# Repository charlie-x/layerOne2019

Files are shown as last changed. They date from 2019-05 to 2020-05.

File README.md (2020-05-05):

View this project on [CADLAB.io](https://cadlab.io/project/22870). 

# layerOne2019
LayerOne 2019 conference www.layerone.org

firmware - folder for kitbadge L1 LOGO see notes in there, 

MOSI, MISO, SCK, VCC, RST, GND

MOSI is closest to top of badge.

firmware for esp32 camera board

https://github.com/m5stack

https://www.youtube.com/watch?v=pfQ5VgcnJhg

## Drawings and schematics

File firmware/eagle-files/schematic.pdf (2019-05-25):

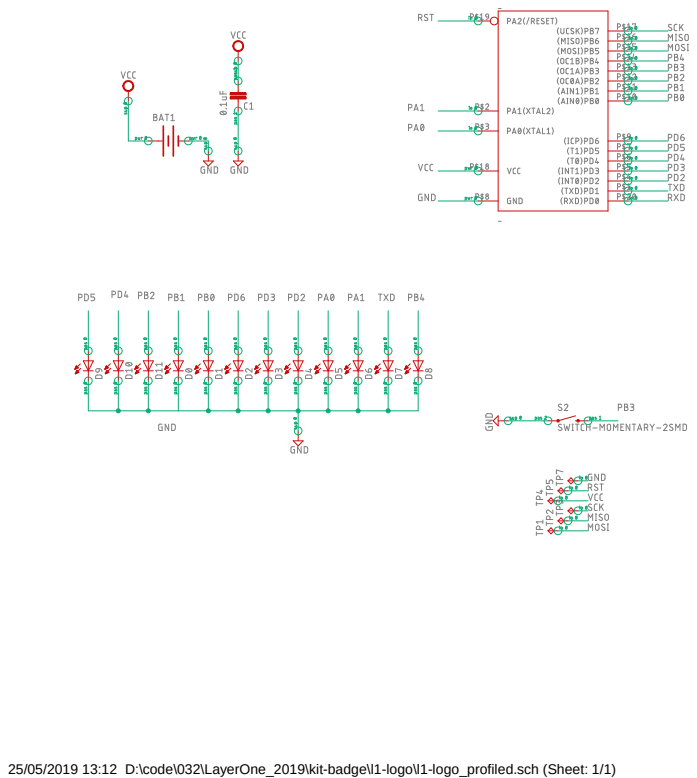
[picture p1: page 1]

25/05/2019 13:12 D:\code\032\LayerOne_2019\kit-badge\l1-logo\l1-logo_profiled.sch (Sheet: 1/1)

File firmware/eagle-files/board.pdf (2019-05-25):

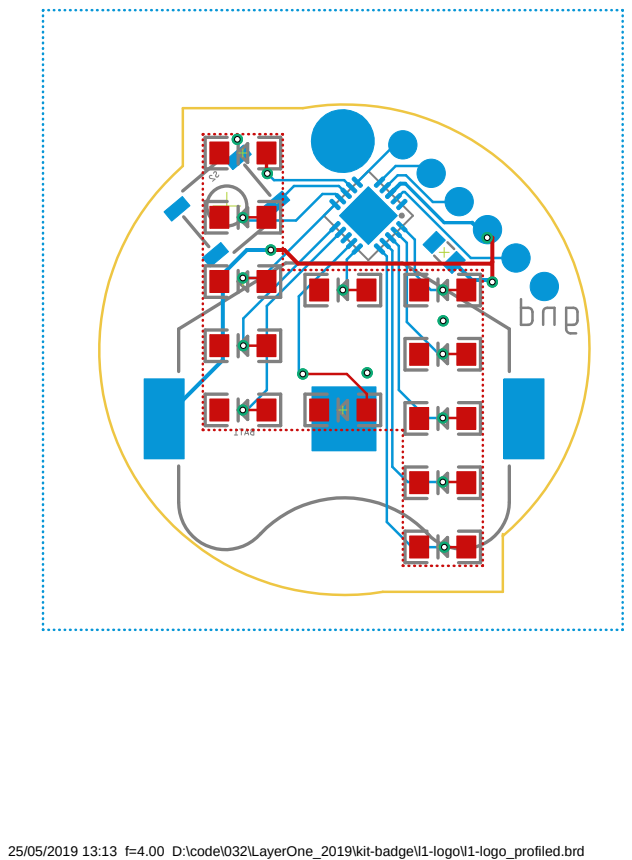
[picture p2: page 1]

25/05/2019 13:13 f=4.00 D:\code\032\LayerOne_2019\kit-badge\l1-logo\l1-logo_profiled.brd

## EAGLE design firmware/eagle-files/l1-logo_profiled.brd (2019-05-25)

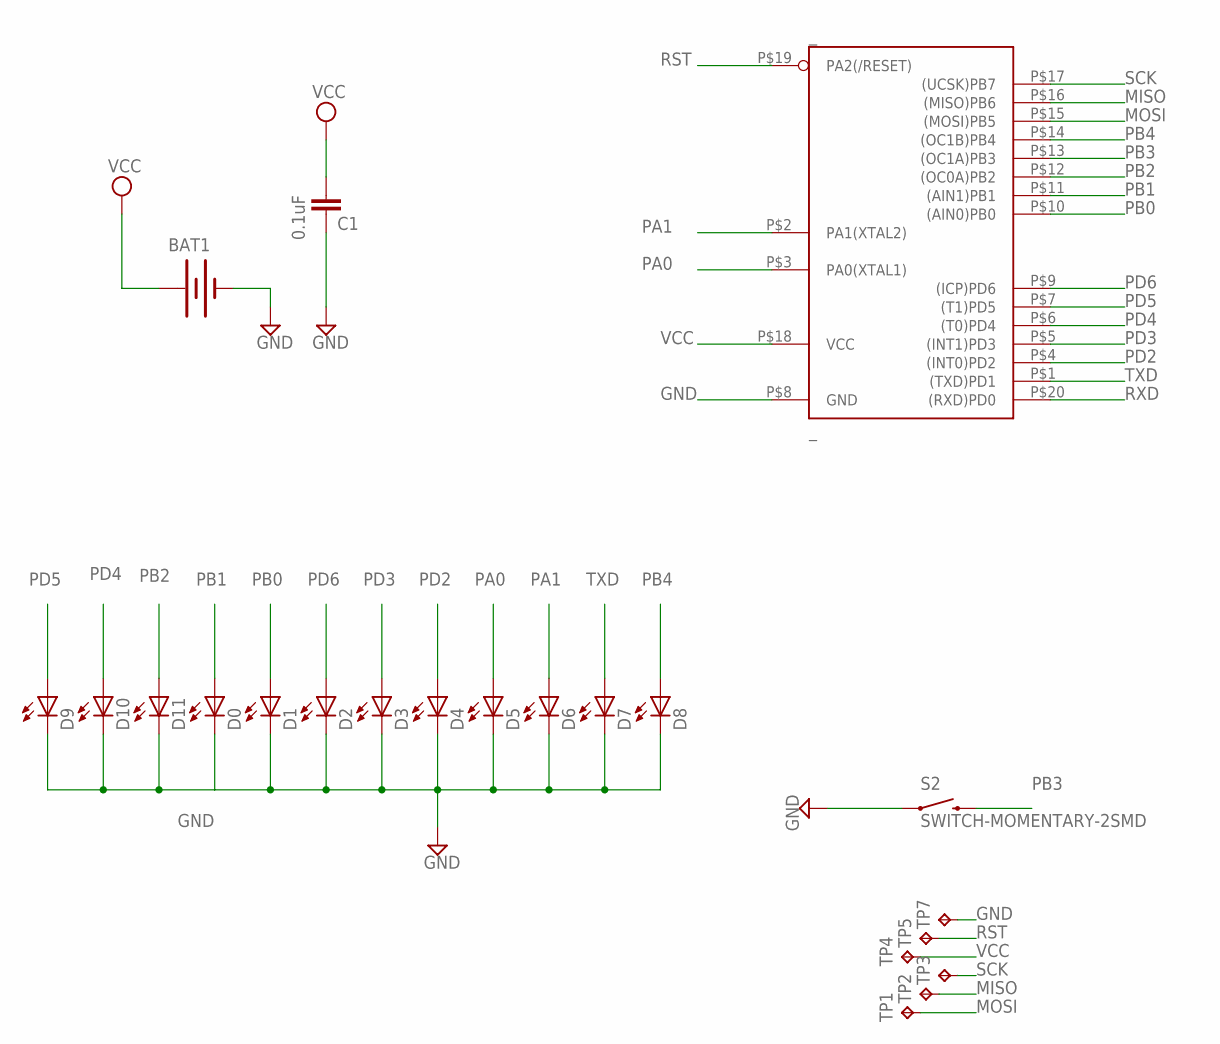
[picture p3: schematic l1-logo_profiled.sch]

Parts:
BAT1: SPARKFUN_BATTERYSPARKFUN_BATTCOMM_20MM_LINX; SPARKFUN_BATTCOM_20MM_LINX
C1: 0.1uF; 0805
D0, D1, D2, D3, D4, D5, D6, D7, D8, D9, D10, D11: SPARKFUN_LED1206; SPARKFUN_LED-1206
S2: SWITCH-MOMENTARY-2SMD; TACTILE_SWITCH_SMD
TP1, TP2, TP3, TP4, TP5, TP7: TPTP18R; TP18R
_: _; MLF20

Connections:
GND: BAT1.2 (-), C1.2, D0.C, D1.C, D2.C, D3.C, D4.C, D5.C, D6.C, D7.C, D8.C, D9.C, D10.C, D11.C, S2.1, TP7.TP, _.P$8 (GND)
MISO: TP2.TP, _.P$16 ((MISO)PB6)
MOSI: TP1.TP, _.P$15 ((MOSI)PB5)
PA0: D5.A, _.P$3 (PA0(XTAL1))
PA1: D6.A, _.P$2 (PA1(XTAL2))
PB0: D1.A, _.P$10 ((AIN0)PB0)
PB1: D0.A, _.P$11 ((AIN1)PB1)
PB2: D11.A, _.P$12 ((OC0A)PB2)
PB3: S2.3 (2), _.P$13 ((OC1A)PB3)
PB4: D8.A, _.P$14 ((OC1B)PB4)
PD2: D4.A, _.P$4 ((INT0)PD2)
PD3: D3.A, _.P$5 ((INT1)PD3)
PD4: D10.A, _.P$6 ((T0)PD4)
PD5: D9.A, _.P$7 ((T1)PD5)
PD6: D2.A, _.P$9 ((ICP)PD6)
RST: TP5.TP, _.P$19 (PA2(/RESET))
RXD: _.P$20 ((RXD)PD0)
SCK: TP3.TP, _.P$17 ((UCSK)PB7)
TXD: D7.A, _.P$1 ((TXD)PD1)
VCC: BAT1.1 (+), C1.1, TP4.TP, _.P$18 (VCC)

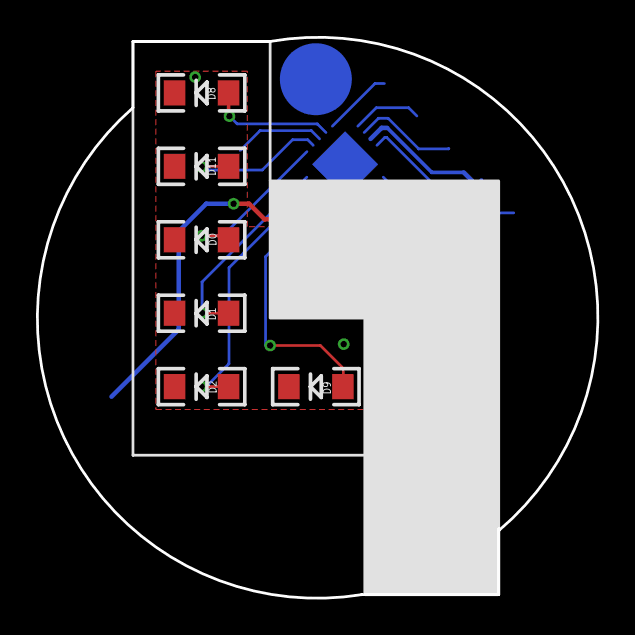
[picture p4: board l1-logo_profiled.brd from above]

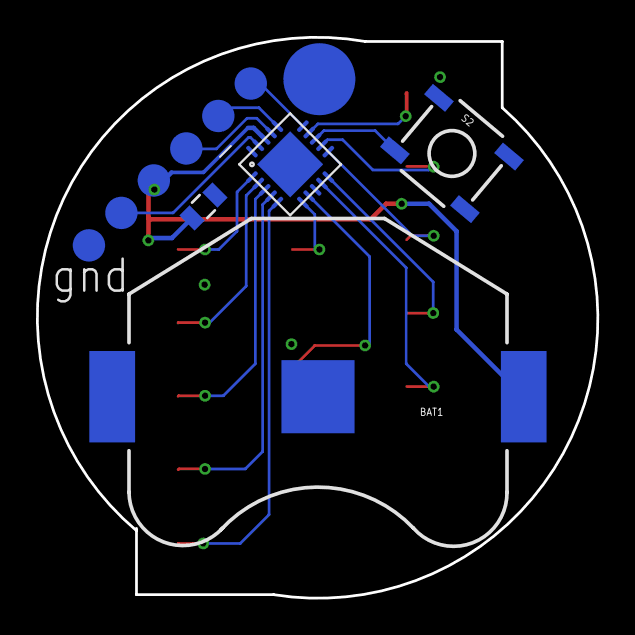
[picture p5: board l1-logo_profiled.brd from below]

Board: 2 copper layers, 31.1 x 31.2 mm, 22 parts (10 on the bottom side), 19 nets.

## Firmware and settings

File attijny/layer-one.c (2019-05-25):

/*
	SELFPRGEN = [ ]
	DWEN = [ ]
	EESAVE = [X]
	SPIEN = [X]
	WDTON = [ ]
	BODLEVEL = DISABLED
	RSTDISBL = [ ]
	CKDIV8 = [ ]
	CKOUT = [ ]
	SUT_CKSEL = INTRCOSC_8MHZ_14CK_0MS

	EXTENDED = 0xFF (valid)
	HIGH = 0x9F (valid)
	LOW = 0xC4 (valid)
*/

#define F_CPU					(8000000UL)

#include <avr/io.h>
#include <avr/eeprom.h>
#include <avr/interrupt.h>
#include <avr/pgmspace.h>
#include <util/delay.h>
#include <string.h>
#include <stdlib.h>

#undef RGB
#define RGB(b,r,g)				((uint32_t)(((uint8_t)(r)|((uint16_t)((uint8_t)(g))<<8))|(((uint32_t)(uint8_t)(b))<<16)))

#define bit_get(p,m)			((p) & (m))
#define bit_set(p,m)			((p) |= (m))
#define bit_clear(p,m)			((p) &= ~(m))
#define bit_flip(p,m)			((p) ^= (m))

// PORTD
#define RED_LED_0				(2)
#define RED_LED_1				(3)
#define RED_LED_2				(4)
#define RED_LED_3				(5)
#define RED_LED_4				(6)

// PORTB
#define RED_LED_5				(0)

#define NUM_RGB_LEDS			(14)
#define	StripLights_MAX_X		(14)

#define shortdelay(); 			asm("nop\n\tnop\n\t");

#define TIMER1_PRESCALE_1 		(1)
#define TIMER1_PRESCALE_8 		(2)
#define TIMER1_PRESCALE_64 		(3)
#define TIMER1_PRESCALE_256		(4)
#define TIMER1_PRESCALE_1024	(5)

#define MIN_OF(x,y)				((x) < (y) ? (x) : (y))
#define MAX_OF(x,y)				((x) > (y) ? (x) : (y))

#define GET_BIT(a,n)			((a >> n) & 1)
#define SET_BIT(a,n)			(a|=(1<<n))
#define CLR_BIT(a,n)			(a&=~(1<<n))
#define SWITCH_BIT(a,n)			(a^=(1<<n))
#define IS_BIT_SET(a,n)			(a & (1<<n))
#define IS_BIT_CLR(a,n)			(~(a & (1<<n)))

#define Red(c)					((uint8_t)((c >> 16) & 0xFF))
#define Green(c)				((uint8_t)((c >> 8)  & 0xFF))
#define Blue(c)					((uint8_t)( c        & 0xFF))

// 		PORTB,DDRB,PIN
#define HEX__(n)				0x##n##LU

/* 8-bit conversion function */
#define B8__(x) ((x&0x0000000FLU)?1:0)	\
	+((x&0x000000F0LU)?2:0)		\
	+((x&0x00000F00LU)?4:0)		\
	+((x&0x0000F000LU)?8:0)		\
	+((x&0x000F0000LU)?16:0)	\
	+((x&0x00F00000LU)?32:0)	\
	+((x&0x0F000000LU)?64:0)	\
	+((x&0xF0000000LU)?128:0)

/* *** user macros ***/

/* for upto 8-bit binary constants */
#define B8(d)					((unsigned char)B8__(HEX__(d)))

/* for upto 16-bit binary constants, MSB first */
#define B16(dmsb,dlsb)			(((unsigned short)B8(dmsb)<<	+ B8(dlsb)))

/* for upto 32-bit binary constants, MSB first */
#define B32(dmsb,db2,db3,dlsb) (((unsigned long)B8(dmsb)<<24)	 \
	+ ((unsigned long)B8(db2)<<16) \
	+ ((unsigned long)B8(db3)<<	 \
	+ B8(dlsb))

#define D6_ON					( 1 << 0 )
#define DD_ON					( 1 << 1 )
#define BO_ON					( D6_ON | DD_ON )

void send ( const void *values, uint16_t array_size, uint8_t bit );

volatile uint8_t counter = 0;// interrupt needs volatile variable
volatile uint8_t counter2 = 0;// interrupt needs volatile variable , counter2 for effects

static uint8_t  rotate = 1;

unsigned char data[NUM_RGB_LEDS * 3] ;

// length of rainbow effect
uint8_t effectLength = 1;

//rotate left, barrel shift
uint8_t inline rotl32a ( uint8_t x, uint8_t n )
{
    return ( x << n ) | ( x >> ( 8 - n ) );
}

////////////////////////////////////////////////////////////////////////////////////////////

void StripLights_Pixel ( uint8_t x, uint32_t color )
{	
    if ( x >= 0 && x < StripLights_MAX_X  ) {
        data[ ( x * 3 )     ] = (color       & 0xFF) >> 3 ;
        data[ ( x * 3 ) + 1 ] = (color >>  8 & 0xFF) >> 3 ;
        data[ ( x * 3 ) + 2 ] = (color >> 16 & 0xFF) >> 3 ;
    }
}

void inline StripLights_Trigger ( uint8_t t )
{
    send ( &data,  NUM_RGB_LEDS, 1 );
}

void inline StripLights_MemClear ( uint32_t d )
{
    memset ( &data[0], d, sizeof ( data ) );
}

////////////////////////////////////////////////////////////////////////////////////////////

static  uint8_t mode = 0;

ISR ( TIMER0_OVF_vect )
{
    if ( ++counter > 30 ) {

        // second counter to control rgb rainbow effect
        if ( ++counter2 > 60 ) {

            effectLength++;

            counter2 = 0;
            SWITCH_BIT ( PORTB , 3 );

            mode = rand() % 3;
        }

        // rotate around
        rotate = rotl32a ( rotate , 1 );

        // reset rotate when we hit this bit position.
        if ( rotate == B8 ( 1000000 ) ) { rotate  = 1;}

        if ( bit_get ( rotate, _BV ( 0 ) ) ) {
            bit_set ( PORTD, _BV ( RED_LED_0 ) );
        } else {
            bit_clear ( PORTD, _BV ( RED_LED_0 ) );
        }

        if ( bit_get ( rotate, _BV ( 1 ) ) ) {
            bit_set ( PORTD, _BV ( RED_LED_1 ) );
        } else {
            bit_clear ( PORTD, _BV ( RED_LED_1 ) );
        }

        if ( bit_get ( rotate, _BV ( 2 ) ) ) {
            bit_set ( PORTD, _BV ( RED_LED_2 ) );
        } else {
            bit_clear ( PORTD, _BV ( RED_LED_2 ) );
        }

        if ( bit_get ( rotate, _BV ( 3 ) ) ) {
            bit_set ( PORTD, _BV ( RED_LED_3 ) );
        } else {
            bit_clear ( PORTD, _BV ( RED_LED_3 ) );
        }

        if ( bit_get ( rotate, _BV ( 4 ) ) ) {
            bit_set ( PORTD, _BV ( RED_LED_4 ) );
        } else {
            bit_clear ( PORTD, _BV ( RED_LED_4 ) );
        }

        if ( bit_get ( rotate, _BV ( 5 ) ) ) {
            bit_set ( PORTB, _BV ( RED_LED_5 ) );
        } else {
            bit_clear ( PORTB, _BV ( RED_LED_5 ) );
        }

        SWITCH_BIT ( PORTB , 2 );
 
		//reset the counter
        counter = 0;
    }
}

uint32_t inline newColor ( uint8_t r, uint8_t g, uint8_t b )
{
    return ( ( ( uint32_t ) ( r ) << 16 ) | ( ( uint32_t ) ( g ) <<  8 ) | ( b ) );
}

uint32_t Wheel ( uint8_t WheelPos )
{
    WheelPos = 255 - WheelPos;

    if ( WheelPos < 85 ) {
        return newColor ( 255 - WheelPos * 3, 0, WheelPos * 3 );
    }

    if ( WheelPos < 170 ) {
        WheelPos -= 85;
        return newColor ( 0, WheelPos * 3, 255 - WheelPos * 3 );
    }

    WheelPos -= 170;
    return newColor ( WheelPos * 3, 255 - WheelPos * 3, 0 );
}

void Rainbow ( uint32_t length , uint32_t effectLengthR )
{
    static uint16_t  x = 0;

    x += 1;

    if ( x == ( 256 * 5 ) ) {
        x = 0;
    }

    for ( uint8_t i = 0 ; i < length ; i++ ) {

        uint32_t color = Wheel ( ( ( i * 256 ) / effectLengthR + x ) & 0xFF );

        StripLights_Pixel ( i, color );
    }
}

static int8_t pos = 0, dir = 1; // Position, direction of "eye"

void Larson ( uint8_t count  )
{
    for ( uint8_t j = 0; j < count; j++ ) {

        // Draw 5 pixels centered on pos.  setPixelColor() will clip any
        // pixels off the ends of the strip, we don't need to watch for that.
        StripLights_Pixel ( pos - 2, 	RGB ( 0x10, 0x00, 0x00 ) ); // Dark red
        StripLights_Pixel ( pos - 1, 	RGB ( 0x80, 0x00, 0x00 ) ); // Medium red
        StripLights_Pixel ( pos, 		RGB ( 0xFF, 0x30, 0x00 ) ); // Center pixel is brightest
        StripLights_Pixel ( pos + 1, 	RGB ( 0x80, 0x00, 0x00 ) ); // Medium red
        StripLights_Pixel ( pos + 2, 	RGB ( 0x10, 0x00, 0x00 ) ); // Dark red

        StripLights_Trigger ( 1 );

        _delay_ms ( 60 );

        // Rather than being sneaky and erasing just the tail pixel,
        // it's easier to erase it all and draw a new one next time.
        //StripLights_MemClear ( 0 );

        // Using this instead of the memclear would leave a trail behind it.
        //FadeStrip(StripLights_MIN_X, StripLights_MAX_X, 6);

        // Bounce off ends of strip
        pos += dir;

        if ( pos < 0 ) {
            pos = 1;
            dir = -dir;

        } else
            if ( pos >= StripLights_MAX_X ) {
                pos = StripLights_MAX_X - 2;
                dir = -dir;
            }
    }
}

int main ( void )
{
    ACSR = 0;

    PORTD = 0;
    PORTB = 0;

    // setup leds and rgb leds
    DDRD = _BV ( 1 ) | _BV ( 2  ) | _BV ( 3  ) | _BV ( 4  ) | _BV ( 5  ) | _BV ( 6  );
    DDRB = _BV ( 0 ) | _BV ( 1 ) | _BV ( 2  ) | _BV ( 3  ) ;

    cli();

    // set prescale timer
    TCCR0B |= ( 1 << CS01 ) | ( 1 << CS00 );

    // enable timer overflow interrupt
    TIMSK |= 1 << TOIE0; // left shift 1 to TOIE0 and OR with TIMSK

    sei(); //start timer

    while ( 1 ) {
		
        switch ( mode ) {

            case 0:
                send ( &data,  NUM_RGB_LEDS, 1 );
                Rainbow ( NUM_RGB_LEDS, effectLength );
                break;

            case 1:
                Larson ( 100 );
                _delay_ms ( 100 );
                break;

            case 2:
                send ( &data,  NUM_RGB_LEDS, 1 );
                Rainbow ( NUM_RGB_LEDS, 1 );
                break;
        }
    }
}

// this is very dependent on xtal clock speed, see fuse settings above

//
// Copyright (c) 2013 Danny Havenith
//
// Distributed under the Boost Software License, Version 1.0. (See accompanying
// file LICENSE_1_0.txt or copy at http://www.boost.org/LICENSE_1_0.txt)
//

/**
 * Library for bit-banging data to WS2811 led controllers.
 * This file contains a definition of the send() function for 8 Mhz controllers.
 */

#define WS2811_PORT PORTD

typedef struct rgb_t {
    uint8_t r, g, b;
} rgb;

/**
* This function sends the RGB - data in an array of rgb structs through
* the given io - pin.
* The port is determined by the macro WS2811_PORT, but the actual pin to
* be used is an argument to this function. This allows a single instance of this function
* to control up to 8 separate channels.
*/
void send ( const void *values, uint16_t array_size, uint8_t bit )
{
    const uint8_t mask = _BV ( bit );
    uint8_t low_val = WS2811_PORT & ( ~mask );
    uint8_t high_val = WS2811_PORT | mask;
    uint16_t size = array_size * sizeof ( rgb ); // size in bytes


// reset the controllers by pulling the data line low
    uint8_t bitcount = 7;
    WS2811_PORT = low_val;
    _delay_loop_1 ( 107 ); // at 3 clocks per iteration, this is 320 ticks or 40us at 8Mhz

// The labels in this piece of assembly code aren't very explanatory. The real documentation
// of this code can be found in the spreadsheet ws2811@8Mhz.ods
// A hint if you still want to follow the code below:
// The code will send bits from most significant to least significant (bits 7 to 0) and consists
// of two variants of the main loop:
// 1) The code for a regular bit (i.e. bits 7-1) starts at label s00 with the current bit value
// already in the carry flag and it jumps halfway back to label cont06.
// 2) For a part of bit 1 and all of bit 0, the code falls through (after the skip03 label)
// where the code needs to fork in a "transmit 0" and "transmit 1" branch. This is because
// there's extra work to be done (loading the next byte), which needs to be carefully placed
// in the time between toggling the output pins.
//
// The two-digit suffix of labels shows the "phase" of the signal at the time
// of the execution, 00 being the first clock tick of the bit and 09 being the last.
    asm volatile (
        "start:  LDI %[bits], 7                          \n" // start code, load bit count
        "        LD __tmp_reg__, %a[dataptr]+            \n" // fetch first byte
        "cont06: NOP                                     \n"
        "cont07: NOP                                     \n"
        "        OUT %[portout], %[downreg]              \n" // Force line down, even if it already was down
        "cont09: LSL __tmp_reg__                         \n" // Load next bit into carry flag.
        "s00:    OUT %[portout], %[upreg]                \n" // Start of bit, bit value is in carry flag
        "        BRCS skip03                             \n" // only lower the line if the bit...
        "        OUT %[portout], %[downreg]              \n" // ...in the carry flag was zero.
        "skip03: SUBI %[bits], 1                         \n" // Decrease bit count...
        "        BRNE cont06                             \n" // ...and loop if not zero
        "        LSL __tmp_reg__                         \n" // Load the last bit into the carry flag
        "        BRCC Lx008                              \n" // Jump if last bit is zero
        "        LDI %[bits], 7                          \n" // Reset bit counter to 7
        "        OUT %[portout], %[downreg]              \n" // Force line down, even if it already was down
        "        NOP                                     \n"
        "        OUT %[portout], %[upreg]                \n" // Start of last bit of byte, which is 1
        "        SBIW %[bytes], 1                        \n" // Decrease byte count
        "        LD __tmp_reg__, %a[dataptr]+            \n" // Load next byte
        "        BRNE cont07                             \n" // Loop if byte count is not zero
        "        RJMP brk18                              \n" // Byte count is zero, jump to the end
        "Lx008:  OUT %[portout], %[downreg]              \n" // Last bit is zero
        "        LDI %[bits], 7                          \n" // Reset bit counter to 7
        "        OUT %[portout], %[upreg]                \n" // Start of last bit of byte, which is 0
        "        NOP                                     \n"
        "        OUT %[portout], %[downreg]              \n" // We know we're transmitting a 0
        "        SBIW %[bytes], 1                        \n" // Decrease byte count
        "        LD __tmp_reg__, %a[dataptr]+            \n"
        "        BRNE cont09                             \n" // Loop if byte count is not zero
        "brk18:  OUT %[portout], %[downreg]              \n"
        "                                                \n" // used to be a NOP here, but returning from the function takes long enough
        "                                                \n" // We're done.
        : /* no output */
        : /* inputs */
        [dataptr] "e" ( values ), 	// pointer to grb values
        [upreg]   "r" ( high_val ),	// register that contains the "up" value for the output port (constant)
        [downreg] "r" ( low_val ),	// register that contains the "down" value for the output port (constant)
        [bytes]   "w" ( size ),		// number of bytes to send
        [bits]    "d" ( bitcount ),     // number of bits/2
        [portout] "I" ( _SFR_IO_ADDR ( WS2811_PORT ) ) // The port to use
    );
}

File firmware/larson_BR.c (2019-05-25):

#if 1

/*
larson.c
The Larson Scanner 

Written by Windell Oskay, http://www.evilmadscientist.com/

 Copyright 2009 Windell H. Oskay
 Distributed under the terms of the GNU General Public License, please see below.
 
 

 An avr-gcc program for the Atmel ATTiny2313  
 
 Version 1.3   Last Modified:  2/8/2009. 
 Written for Evil Mad Science Larson Scanner Kit, based on the "ix" circuit board. 
 
 Improvements in v 1.3:
 * EEPROM is used to *correctly* remember last speed & brightness mode.
 
 Improvements in v 1.2:
 * Skinny "eye" mode.  Hold button at turn-on to try this mode.  To make it default,
 solder jumper "Opt 1."  (If skinny mode is default, holding button will disable it temporarily.)
 * EEPROM is used to remember last speed & brightness mode.
 
 
 More information about this project is at 
 http://www.evilmadscientist.com/article.php/larsonkit
 
 
 
 -------------------------------------------------
 USAGE: How to compile and install
 
 
 
 A makefile is provided to compile and install this program using AVR-GCC and avrdude.
 
 To use it, follow these steps:
 1. Update the header of the makefile as needed to reflect the type of AVR programmer that you use.
 2. Open a terminal window and move into the directory with this file and the makefile.  
 3. At the terminal enter
 make clean   <return>
 make all     <return>
 make install <return>
 4. Make sure that avrdude does not report any errors.  If all goes well, the last few lines output by avrdude
 should look something like this:
 
 avrdude: verifying ...
 avrdude: XXXX bytes of flash verified
 
 avrdude: safemode: lfuse reads as 62
 avrdude: safemode: hfuse reads as DF
 avrdude: safemode: efuse reads as FF
 avrdude: safemode: Fuses OK
 
 avrdude done.  Thank you.
 
 
 If you a different programming environment, make sure that you copy over the fuse settings from the makefile.
 
 
 -------------------------------------------------
 
 This code should be relatively straightforward, so not much documentation is provided.  If you'd like to ask 
 questions, suggest improvements, or report success, please use the evilmadscientist forum:
 http://www.evilmadscientist.com/forum/
 
 
 -------------------------------------------------
 
  
*/

#include <avr/io.h> 
#include <avr/eeprom.h> 
#include <avr/interrupt.h>
#include <avr/pgmspace.h>
#include <util/delay.h>

#define shortdelay(); 			asm("nop\n\t" \
"nop\n\t");

#define TIMER1_PRESCALE_1 		(1)
#define TIMER1_PRESCALE_8 		(2)
#define TIMER1_PRESCALE_64 		(3)
#define TIMER1_PRESCALE_256		(4)
#define TIMER1_PRESCALE_1024	(5)

uint16_t eepromWord __attribute__((section(".eeprom")));

int main (void)
{
	uint8_t LEDs[9]; // Storage for current LED values
	
	int8_t eyeLoc[5]; // List of which LED has each role, leading edge through tail.

	uint8_t LEDBright[4] = {1U,4U,2U,1U};   // Relative brightness of scanning eye positions
	


	int8_t j, m;
	
	uint8_t position, loopcount, direction;
	uint8_t ILED, RLED, MLED;

	uint8_t delaytime;
	
	uint8_t skinnyEye = 0;
	uint8_t  pt, debounce, speedLevel;
	uint8_t 	UpdateConfig;
	uint8_t BrightMode;
	uint8_t debounce2, modeswitched;
	
	uint8_t CycleCountLow;  
	uint8_t LED0, LED1, LED2, LED3, LED4, LED5, LED6, LED7, LED8;
	
	//Initialization routine: Clear watchdog timer-- this can prevent several things from going wrong.		
	MCUSR &= 0xF7;		//Clear WDRF Flag
	WDTCSR	= 0x18;		//Set stupid bits so we can clear timer...
	WDTCSR	= 0x00;

	//Data direction register: DDR's
	//Port A: 0, 1 are inputs.	
	//Port B: 0-3 are outputs, B4 is an input.
	//Port D: 1-6 are outputs, D0 is an input.
	
	DDRA = 0U;
	DDRB = 15U;	
	DDRD = 126U;
	
	PORTA = 3;	// Pull-up resistors enabled, PA0, PA1
	PORTB = 16;	// Pull-up resistor enabled, PA
	PORTD = 0;
		
  TCCR1B = (1 << WGM12) | TIMER1_PRESCALE_1;
  OCR1A = (uint16_t)1250;

  TIMSK |= 1 << OCIE1A;   // Output Compare Interrupt Enable (timer 1, OCR1A) 

	/* Visualize outputs:
 
	 L to R:
 
	 D2 D3 D4 D5 D6 B0 B1 B2 B3	
  
	*/
	
	//multiplexed = LowPower;	
 
	debounce = 0; 
	debounce2 = 0;
	loopcount = 254; 
	delaytime = 0;
	
	direction = 0;
	position = 0;
	speedLevel = 0;  // Range: 1, 2, 3
	BrightMode = 0;
	CycleCountLow = 0;
	UpdateConfig = 0;
	modeswitched = 0;
	
	
	if ((PINA & 2) == 0)		// Check if Jumper 1, at location PA1 is shorted
	{  
		// Optional place to do something.  :)
	}
	
	
	
	if ((PINA & 1) == 0)		// Check if Jumper 2, at location PA0 is shorted
	{    
		skinnyEye = 1; 
	}	
	
	
	if ((PINB & 16) == 0)		// Check if button pressed pressed down at turn-on
	{		

	//Toggle Skinnymode
		if (skinnyEye)
			skinnyEye = 0; 
		else 
			skinnyEye = 1;
	}
	
	
	
	if (skinnyEye){
		LEDBright[0] = 0;
		LEDBright[1] = 4;	
		LEDBright[2] = 1;
		LEDBright[3] = 0;  
	}
	
	
	//Check EEPROM values:
	
	pt = (uint8_t) (eeprom_read_word(&eepromWord)) ;
	speedLevel = pt >> 4;
	BrightMode = pt & 1;

	if (pt == 0xFF)
	{
		BrightMode = 0;
	}
	
	
	if (speedLevel > 3)
		speedLevel = 1; 
	
	speedLevel = 0;

	if ((speedLevel == 2) || (speedLevel == 3)) { 
		delaytime = 0;
	} 
	else 
	{   speedLevel = 1; 
		delaytime = 1;
	}
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

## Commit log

2019-05-25 kitbadge mini l1 logo firmware
    binary counter, larson.c is the main file. atmel studio and avr studio added.
    program is MOSI, MISO, SCK, VCC, RST,GND
    MOSI is closest to top of badge.
2019-05-25 added eagle files and pdfs for board and schematic
    [l1-logo_profiled.brd, l1-logo_profiled.sch]

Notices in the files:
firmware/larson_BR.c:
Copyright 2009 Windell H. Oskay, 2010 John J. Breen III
